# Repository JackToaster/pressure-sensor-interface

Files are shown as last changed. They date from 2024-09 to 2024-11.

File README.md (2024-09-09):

# Pressure Sensor Interface

This repository contains PCB designs & firmware (WIP) for an 8-channel USB pressure sensor/solenoid valve driver.

## Features

(Note that this is still in the early prototype stage so these specs have not been validated yet)

**8x pressure sensors**

- using the LWPxxx series of low-cost piezoresistive pressure sensors
- HX711 Load cell amplifier to read output
  - Note the full scale range of the pressure sensor is wider than the input range of the HX711 - This means the full range of the sensor may be impossible to read, but this is an acceptable tradeoff for the extremely low cost.
  - Capable of up to 144Hz sampling rate
 
**8x Solenoid Valve Drivers**

- Low-side NMOS switches
- Capable of ~4A per channel
- Separate DC power input for solenoid valves, supports 0-24VDC (Limited by 30V Vds rating of FET)
- Individual PWM control of each channel

**STM32F103 Microcontroller + USB-C**

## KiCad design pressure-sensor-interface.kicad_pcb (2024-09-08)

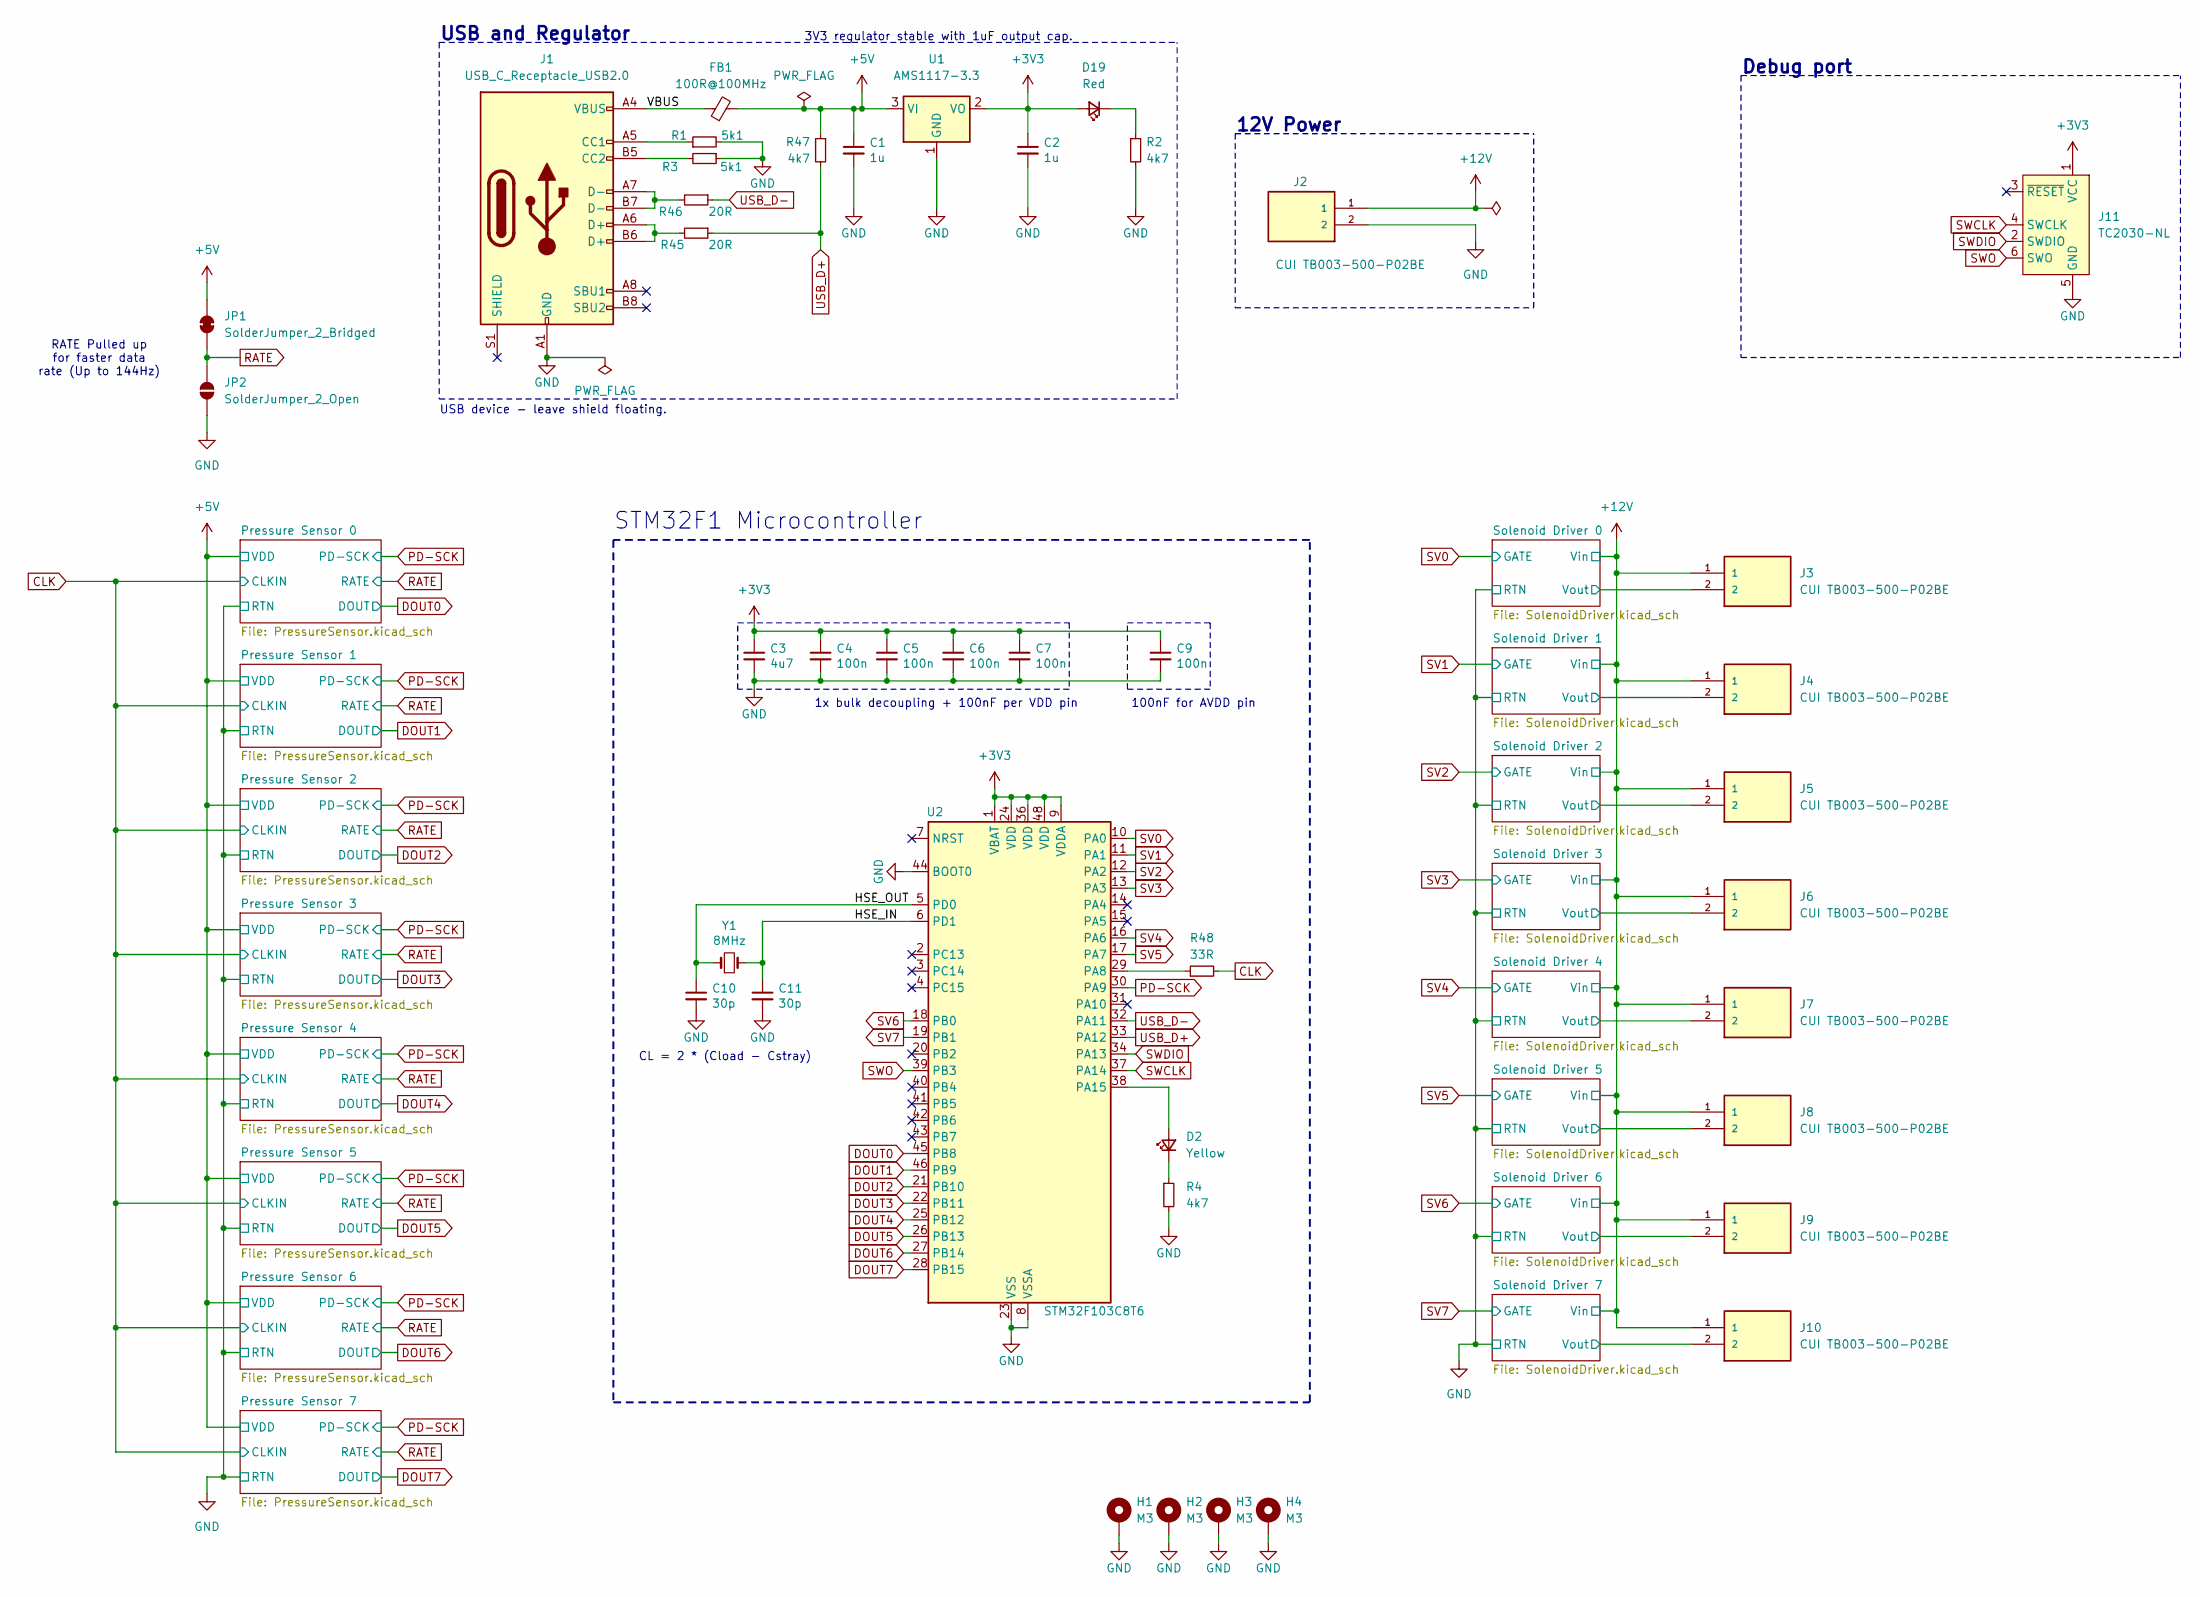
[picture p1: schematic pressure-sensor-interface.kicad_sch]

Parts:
C1, C2: 1u; C_0603_1608Metric; LCSC C15849
C3: 4u7; C_0603_1608Metric; LCSC C19666
C4, C5, C6, C7, C9: 100n; C_0603_1608Metric; LCSC C307331
C10, C11: 30p; C_0603_1608Metric; LCSC C1570
D2: Yellow; LED_0603_1608Metric
D19: Red; LED_0603_1608Metric
FB1: 100R@100MHz; R_0805_2012Metric; LCSC C1015
H1, H2, H3, H4: M3; MountingHole_2.2mm_M2_Pad_Via
J1: USB_C_Receptacle_USB2.0; USB_C_Receptacle_HRO_TYPE-C-31-M-12; LCSC C165948
J2, J3, J4, J5, J6, J7, J8, J9, J10: CUI TB003-500-P02BE; CUI_TB003-500-P02BE
J11: TC2030-NL; Tag-Connect_TC2030-IDC-NL_2x03_P1.27mm_Vertical
JP1: SolderJumper_2_Bridged; SolderJumper-2_P1.3mm_Bridged_Pad1.0x1.5mm
JP2: SolderJumper_2_Open; SolderJumper-2_P1.3mm_Open_TrianglePad1.0x1.5mm
R1, R3: 5k1; R_0603_1608Metric; LCSC C25905
R2, R4, R47: 4k7; R_0603_1608Metric
R45, R46: 20R; R_0603_1608Metric; LCSC C25905
R48: 33R; R_0603_1608Metric
U1: AMS1117-3.3; SOT-223-3_TabPin2; LCSC C6186
U2: STM32F103C8T6; LQFP-48_7x7mm_P0.5mm; LCSC C77994
Y1: 8MHz; Crystal_SMD_5032-2Pin_5.0x3.2mm; LCSC C115962

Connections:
+3V3: C2.1, C3.1, C4.1, C5.1, C6.1, C7.1, C9.1, D19.2 (A), J11.1 (VCC), U1.2 (VO), U2.1 (VBAT), U2.9 (VDDA), U2.24 (VDD), U2.36 (VDD), U2.48 (VDD)
+5V: C1.1, FB1.2, JP1.2 (B), R47.1, U1.3 (VI); also elsewhere on the board
+12V: J2.1, J3.1, J4.1, J5.1, J6.1, J7.1, J8.1, J9.1, J10.1; also elsewhere on the board
/HSE_IN: C11.1, U2.6 (PD1), Y1.2
/HSE_OUT: C10.1, U2.5 (PD0), Y1.1
/Solenoid Driver 0/Vout: J3.2; also elsewhere on the board
/Solenoid Driver 1/Vout: J4.2; also elsewhere on the board
/Solenoid Driver 2/Vout: J5.2; also elsewhere on the board
/Solenoid Driver 3/Vout: J6.2; also elsewhere on the board
/Solenoid Driver 4/Vout: J7.2; also elsewhere on the board
/Solenoid Driver 5/Vout: J8.2; also elsewhere on the board
/Solenoid Driver 6/Vout: J9.2; also elsewhere on the board
/Solenoid Driver 7/Vout: J10.2; also elsewhere on the board
/VBUS: FB1.1, J1.A4 (VBUS), J1.A9 (VBUS), J1.B4 (VBUS), J1.B9 (VBUS)
CLK: R48.2; also elsewhere on the board
DOUT0: U2.45 (PB8); also elsewhere on the board
DOUT1: U2.46 (PB9); also elsewhere on the board
DOUT2: U2.21 (PB10); also elsewhere on the board
DOUT3: U2.22 (PB11); also elsewhere on the board
DOUT4: U2.25 (PB12); also elsewhere on the board
DOUT5: U2.26 (PB13); also elsewhere on the board
DOUT6: U2.27 (PB14); also elsewhere on the board
DOUT7: U2.28 (PB15); also elsewhere on the board
GND: C1.2, C2.2, C3.2, C4.2, C5.2, C6.2, C7.2, C9.2, C10.2, C11.2, H1.1, H2.1, H3.1, H4.1, J1.A1 (GND), J1.A12 (GND), J1.B1 (GND), J1.B12 (GND), J2.2, J11.5 (GND), JP2.1 (A), R1.2, R2.2, R3.1, R4.2, U1.1 (GND), U2.8 (VSSA), U2.23 (VSS), U2.35 (VSS), U2.44 (BOOT0), U2.47 (VSS); also elsewhere on the board
unnamed: D2.2 (A), U2.38 (PA15)
unnamed: D2.1 (K), R4.1
unnamed: D19.1 (K), R2.1
unnamed: J1.A5 (CC1), R1.1
unnamed: J1.B5 (CC2), R3.2
unnamed: J1.A6 (D+), J1.B6 (D+), R45.2
unnamed: J1.A7 (D-), J1.B7 (D-), R46.2
unnamed: R48.1, U2.29 (PA8)
PD-SCK: U2.30 (PA9); also elsewhere on the board
RATE: JP1.1 (A), JP2.2 (B); also elsewhere on the board
SV0: U2.10 (PA0); also elsewhere on the board
SV1: U2.11 (PA1); also elsewhere on the board
SV2: U2.12 (PA2); also elsewhere on the board
SV3: U2.13 (PA3); also elsewhere on the board
SV4: U2.16 (PA6); also elsewhere on the board
SV5: U2.17 (PA7); also elsewhere on the board
SV6: U2.18 (PB0); also elsewhere on the board
SV7: U2.19 (PB1); also elsewhere on the board
SWCLK: J11.4 (SWCLK), U2.37 (PA14)
SWDIO: J11.2 (SWDIO), U2.34 (PA13)
SWO: J11.6 (SWO), U2.39 (PB3)
USB_D+: R45.1, R47.2, U2.33 (PA12)
USB_D-: R46.1, U2.32 (PA11)

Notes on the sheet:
12V Power
Debug port
USB and Regulator
3V3 regulator stable with 1uF output cap.
RATE Pulled up for faster data rate (Up to 144Hz)
100nF for AVDD pin
1x bulk decoupling + 100nF per VDD pin
CL = 2 * (Cload - Cstray)
STM32F1 Microcontroller
USB device - leave shield floating.

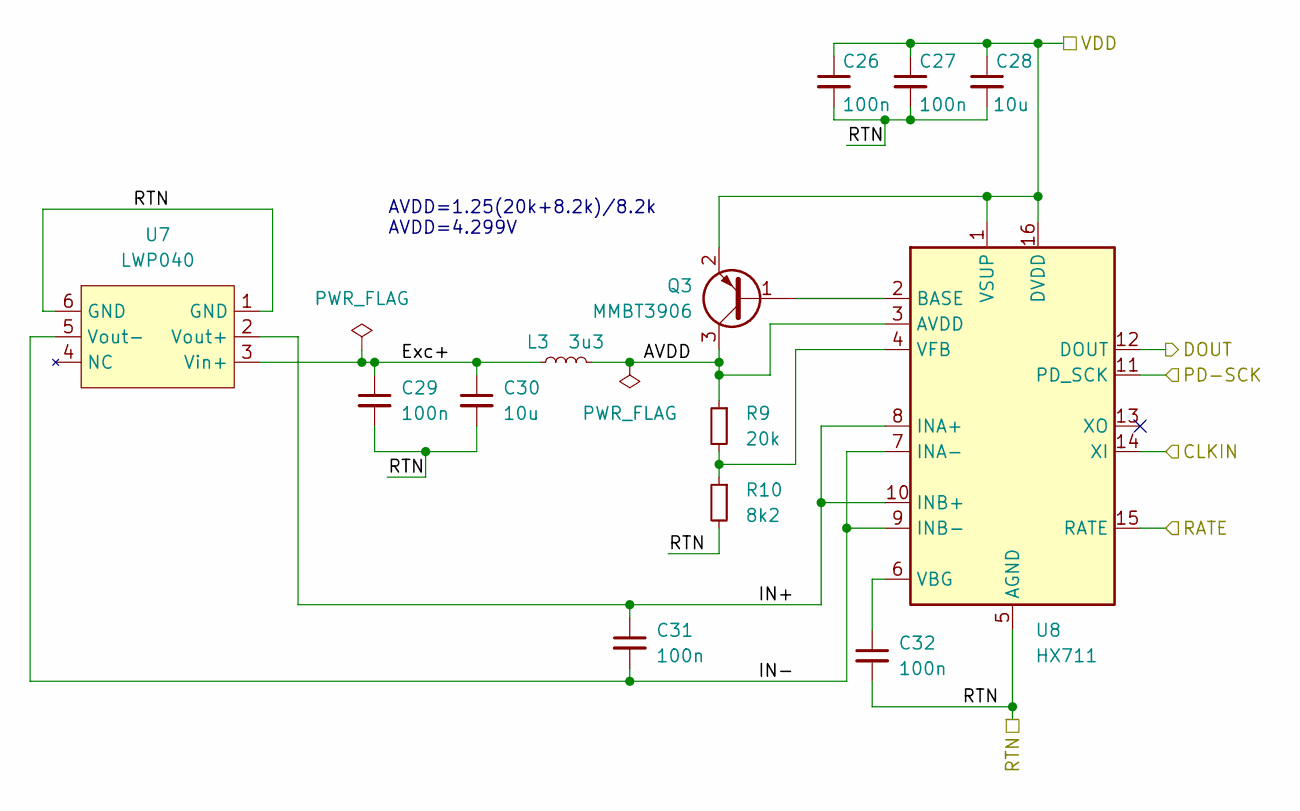
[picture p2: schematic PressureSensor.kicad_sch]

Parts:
C26, C27, C29, C31, C32: 100n; C_0603_1608Metric
C28, C30: 10u; C_0603_1608Metric
L3: 3u3; L_0603_1608Metric
Q3: MMBT3906; SOT-23
R9: 20k; R_0603_1608Metric
R10: 8k2; R_0603_1608Metric
U7: LWP040; SOIC-6-Pressure-Sensor
U8: HX711; SOP-16_3.9x9.9mm_P1.27mm

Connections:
+5V: C26.1, C27.1, C28.1, Q3.2 (E), U8.1 (VSUP), U8.16 (DVDD); also elsewhere on the board
/Pressure Sensor 2/AVDD: L3.2, Q3.3 (C), R9.1, U8.3 (AVDD)
/Pressure Sensor 2/Exc+: C29.1, C30.1, L3.1, U7.3 (Vin+)
/Pressure Sensor 2/IN+: C31.1, U7.2 (Vout+), U8.8 (INA+), U8.10 (INB+)
/Pressure Sensor 2/IN-: C31.2, U7.5 (Vout-), U8.7 (INA-), U8.9 (INB-)
CLK: U8.14 (XI); also elsewhere on the board
DOUT2: U8.12 (DOUT); also elsewhere on the board
GND: C26.2, C27.2, C28.2, C29.2, C30.2, C32.2, R10.2, U7.1 (GND), U7.6 (GND), U8.5 (AGND); also elsewhere on the board
unnamed: Q3.1 (B), U8.2 (BASE)
unnamed: C32.1, U8.6 (VBG)
unnamed: R9.2, R10.1, U8.4 (VFB)
PD-SCK: U8.11 (PD_SCK); also elsewhere on the board
RATE: U8.15 (RATE); also elsewhere on the board

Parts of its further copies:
C12, C13, C15, C17, C18, C19, C20, C22, C24, C25, C33, C34, C36, C38, C39, C40, C41, C43, C45, C46, C47, C48, C50, C52, C53, C54, C55, C57, C59, C60, C61, C62, C64, C66, C67: 100n; C_0603_1608Metric
C14, C16, C21, C23, C35, C37, C42, C44, C49, C51, C56, C58, C63, C65: 10u; C_0603_1608Metric
L1, L2, L4, L5, L6, L7, L8: 3u3; L_0603_1608Metric
Q1, Q2, Q4, Q5, Q6, Q7, Q8: MMBT3906; SOT-23
R5, R7, R11, R13, R15, R17, R19: 20k; R_0603_1608Metric
R6, R8, R12, R14, R16, R18, R20: 8k2; R_0603_1608Metric
U3, U5, U9, U11, U13, U15, U17: LWP040; SOIC-6-Pressure-Sensor
U4, U6, U10, U12, U14, U16, U18: HX711; SOP-16_3.9x9.9mm_P1.27mm

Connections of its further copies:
+5V: C12.1, C13.1, C14.1, C19.1, C20.1, C21.1, C33.1, C34.1, C35.1, C40.1, C41.1, C42.1, C47.1, C48.1, C49.1, C54.1, C55.1, C56.1, C61.1, C62.1, C63.1, Q1.2 (E), Q2.2 (E), Q4.2 (E), Q5.2 (E), Q6.2 (E), Q7.2 (E), Q8.2 (E), U4.1 (VSUP), U4.16 (DVDD), U6.1 (VSUP), U6.16 (DVDD), U10.1 (VSUP), U10.16 (DVDD), U12.1 (VSUP), U12.16 (DVDD), U14.1 (VSUP), U14.16 (DVDD), U16.1 (VSUP), U16.16 (DVDD), U18.1 (VSUP), U18.16 (DVDD); also elsewhere on the board
/Pressure Sensor 0/AVDD: L1.2, Q1.3 (C), R5.1, U4.3 (AVDD)
/Pressure Sensor 0/Exc+: C15.1, C16.1, L1.1, U3.3 (Vin+)
/Pressure Sensor 0/IN+: C17.1, U3.2 (Vout+), U4.8 (INA+), U4.10 (INB+)
/Pressure Sensor 0/IN-: C17.2, U3.5 (Vout-), U4.7 (INA-), U4.9 (INB-)
/Pressure Sensor 1/AVDD: L2.2, Q2.3 (C), R7.1, U6.3 (AVDD)
/Pressure Sensor 1/Exc+: C22.1, C23.1, L2.1, U5.3 (Vin+)
/Pressure Sensor 1/IN+: C24.1, U5.2 (Vout+), U6.8 (INA+), U6.10 (INB+)
/Pressure Sensor 1/IN-: C24.2, U5.5 (Vout-), U6.7 (INA-), U6.9 (INB-)
/Pressure Sensor 3/AVDD: L4.2, Q4.3 (C), R11.1, U10.3 (AVDD)
/Pressure Sensor 3/Exc+: C36.1, C37.1, L4.1, U9.3 (Vin+)
/Pressure Sensor 3/IN+: C38.1, U9.2 (Vout+), U10.8 (INA+), U10.10 (INB+)
/Pressure Sensor 3/IN-: C38.2, U9.5 (Vout-), U10.7 (INA-), U10.9 (INB-)
/Pressure Sensor 4/AVDD: L5.2, Q5.3 (C), R13.1, U12.3 (AVDD)
/Pressure Sensor 4/Exc+: C43.1, C44.1, L5.1, U11.3 (Vin+)
/Pressure Sensor 4/IN+: C45.1, U11.2 (Vout+), U12.8 (INA+), U12.10 (INB+)
/Pressure Sensor 4/IN-: C45.2, U11.5 (Vout-), U12.7 (INA-), U12.9 (INB-)
/Pressure Sensor 5/AVDD: L6.2, Q6.3 (C), R15.1, U14.3 (AVDD)
/Pressure Sensor 5/Exc+: C50.1, C51.1, L6.1, U13.3 (Vin+)
/Pressure Sensor 5/IN+: C52.1, U13.2 (Vout+), U14.8 (INA+), U14.10 (INB+)
/Pressure Sensor 5/IN-: C52.2, U13.5 (Vout-), U14.7 (INA-), U14.9 (INB-)
/Pressure Sensor 6/AVDD: L7.2, Q7.3 (C), R17.1, U16.3 (AVDD)
/Pressure Sensor 6/Exc+: C57.1, C58.1, L7.1, U15.3 (Vin+)
/Pressure Sensor 6/IN+: C59.1, U15.2 (Vout+), U16.8 (INA+), U16.10 (INB+)
/Pressure Sensor 6/IN-: C59.2, U15.5 (Vout-), U16.7 (INA-), U16.9 (INB-)
/Pressure Sensor 7/AVDD: L8.2, Q8.3 (C), R19.1, U18.3 (AVDD)
/Pressure Sensor 7/Exc+: C64.1, C65.1, L8.1, U17.3 (Vin+)
/Pressure Sensor 7/IN+: C66.1, U17.2 (Vout+), U18.8 (INA+), U18.10 (INB+)
/Pressure Sensor 7/IN-: C66.2, U17.5 (Vout-), U18.7 (INA-), U18.9 (INB-)
CLK: U4.14 (XI), U6.14 (XI), U10.14 (XI), U12.14 (XI), U14.14 (XI), U16.14 (XI), U18.14 (XI); also elsewhere on the board
DOUT0: U4.12 (DOUT); also elsewhere on the board
DOUT1: U6.12 (DOUT); also elsewhere on the board
DOUT3: U10.12 (DOUT); also elsewhere on the board
DOUT4: U12.12 (DOUT); also elsewhere on the board
DOUT5: U14.12 (DOUT); also elsewhere on the board
DOUT6: U16.12 (DOUT); also elsewhere on the board
DOUT7: U18.12 (DOUT); also elsewhere on the board
GND: C12.2, C13.2, C14.2, C15.2, C16.2, C18.2, C19.2, C20.2, C21.2, C22.2, C23.2, C25.2, C33.2, C34.2, C35.2, C36.2, C37.2, C39.2, C40.2, C41.2, C42.2, C43.2, C44.2, C46.2, C47.2, C48.2, C49.2, C50.2, C51.2, C53.2, C54.2, C55.2, C56.2, C57.2, C58.2, C60.2, C61.2, C62.2, C63.2, C64.2, C65.2, C67.2, R6.2, R8.2, R12.2, R14.2, R16.2, R18.2, R20.2, U3.1 (GND), U3.6 (GND), U4.5 (AGND), U5.1 (GND), U5.6 (GND), U6.5 (AGND), U9.1 (GND), U9.6 (GND), U10.5 (AGND), U11.1 (GND), U11.6 (GND), U12.5 (AGND), U13.1 (GND), U13.6 (GND), U14.5 (AGND), U15.1 (GND), U15.6 (GND), U16.5 (AGND), U17.1 (GND), U17.6 (GND), U18.5 (AGND); also elsewhere on the board
unnamed: Q1.1 (B), U4.2 (BASE)
unnamed: Q2.1 (B), U6.2 (BASE)
unnamed: Q4.1 (B), U10.2 (BASE)
unnamed: Q5.1 (B), U12.2 (BASE)
unnamed: Q6.1 (B), U14.2 (BASE)
unnamed: Q7.1 (B), U16.2 (BASE)
unnamed: Q8.1 (B), U18.2 (BASE)
unnamed: C18.1, U4.6 (VBG)
unnamed: R5.2, R6.1, U4.4 (VFB)
unnamed: C25.1, U6.6 (VBG)
unnamed: R7.2, R8.1, U6.4 (VFB)
unnamed: C39.1, U10.6 (VBG)
unnamed: R11.2, R12.1, U10.4 (VFB)
unnamed: C46.1, U12.6 (VBG)
unnamed: R13.2, R14.1, U12.4 (VFB)
unnamed: C53.1, U14.6 (VBG)
unnamed: R15.2, R16.1, U14.4 (VFB)
unnamed: C60.1, U16.6 (VBG)
unnamed: R17.2, R18.1, U16.4 (VFB)
unnamed: C67.1, U18.6 (VBG)
unnamed: R19.2, R20.1, U18.4 (VFB)
PD-SCK: U4.11 (PD_SCK), U6.11 (PD_SCK), U10.11 (PD_SCK), U12.11 (PD_SCK), U14.11 (PD_SCK), U16.11 (PD_SCK), U18.11 (PD_SCK); also elsewhere on the board
RATE: U4.15 (RATE), U6.15 (RATE), U10.15 (RATE), U12.15 (RATE), U14.15 (RATE), U16.15 (RATE), U18.15 (RATE); also elsewhere on the board

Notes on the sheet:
AVDD=1.25(20k+8.2k)/8.2k AVDD=4.299V

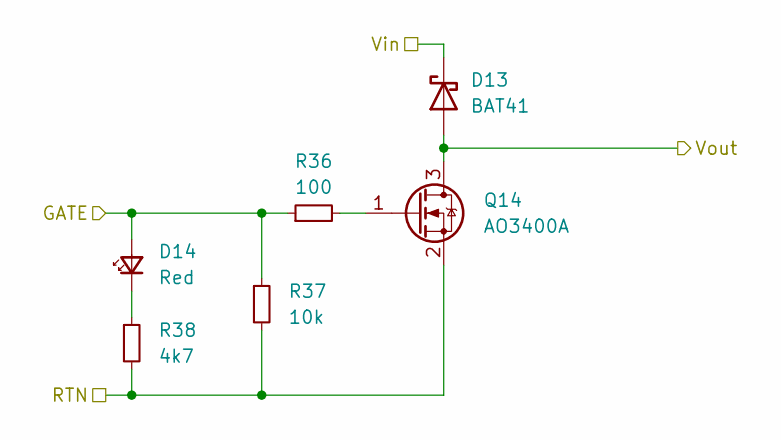
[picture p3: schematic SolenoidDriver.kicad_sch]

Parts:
D13: BAT41; D_SOD-123
D14: Red; LED_0603_1608Metric
Q14: AO3400A; SOT-23
R36: 100; R_0603_1608Metric
R37: 10k; R_0603_1608Metric
R38: 4k7; R_0603_1608Metric

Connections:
+12V: D13.1 (K); also elsewhere on the board
/Solenoid Driver 5/Vout: D13.2 (A), Q14.3 (D); also elsewhere on the board
GND: Q14.2 (S), R37.2, R38.2; also elsewhere on the board
unnamed: D14.1 (K), R38.1
unnamed: Q14.1 (G), R36.2
SV5: D14.2 (A), R36.1, R37.1; also elsewhere on the board

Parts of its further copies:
D3, D5, D7, D9, D11, D15, D17: BAT41; D_SOD-123
D4, D6, D8, D10, D12, D16, D18: Red; LED_0603_1608Metric
Q9, Q10, Q11, Q12, Q13, Q15, Q16: AO3400A; SOT-23
R21, R24, R27, R30, R33, R39, R42: 100; R_0603_1608Metric
R22, R25, R28, R31, R34, R40, R43: 10k; R_0603_1608Metric
R23, R26, R29, R32, R35, R41, R44: 4k7; R_0603_1608Metric

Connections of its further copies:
+12V: D3.1 (K), D5.1 (K), D7.1 (K), D9.1 (K), D11.1 (K), D15.1 (K), D17.1 (K); also elsewhere on the board
/Solenoid Driver 0/Vout: D3.2 (A), Q9.3 (D); also elsewhere on the board
/Solenoid Driver 1/Vout: D5.2 (A), Q10.3 (D); also elsewhere on the board
/Solenoid Driver 2/Vout: D7.2 (A), Q11.3 (D); also elsewhere on the board
/Solenoid Driver 3/Vout: D9.2 (A), Q12.3 (D); also elsewhere on the board
/Solenoid Driver 4/Vout: D11.2 (A), Q13.3 (D); also elsewhere on the board
/Solenoid Driver 6/Vout: D15.2 (A), Q15.3 (D); also elsewhere on the board
/Solenoid Driver 7/Vout: D17.2 (A), Q16.3 (D); also elsewhere on the board
GND: Q9.2 (S), Q10.2 (S), Q11.2 (S), Q12.2 (S), Q13.2 (S), Q15.2 (S), Q16.2 (S), R22.2, R23.2, R25.2, R26.2, R28.2, R29.2, R31.2, R32.2, R34.2, R35.2, R40.2, R41.2, R43.2, R44.2; also elsewhere on the board
unnamed: D4.1 (K), R23.1
unnamed: D6.1 (K), R26.1
unnamed: D8.1 (K), R29.1
unnamed: D10.1 (K), R32.1
unnamed: D12.1 (K), R35.1
unnamed: D16.1 (K), R41.1
unnamed: D18.1 (K), R44.1
unnamed: Q9.1 (G), R21.2
unnamed: Q10.1 (G), R24.2
unnamed: Q11.1 (G), R27.2
unnamed: Q12.1 (G), R30.2
unnamed: Q13.1 (G), R33.2
unnamed: Q15.1 (G), R39.2
unnamed: Q16.1 (G), R42.2
SV0: D4.2 (A), R21.1, R22.1; also elsewhere on the board
SV1: D6.2 (A), R24.1, R25.1; also elsewhere on the board
SV2: D8.2 (A), R27.1, R28.1; also elsewhere on the board
SV3: D10.2 (A), R30.1, R31.1; also elsewhere on the board
SV4: D12.2 (A), R33.1, R34.1; also elsewhere on the board
SV6: D16.2 (A), R39.1, R40.1; also elsewhere on the board
SV7: D18.2 (A), R42.1, R43.1; also elsewhere on the board

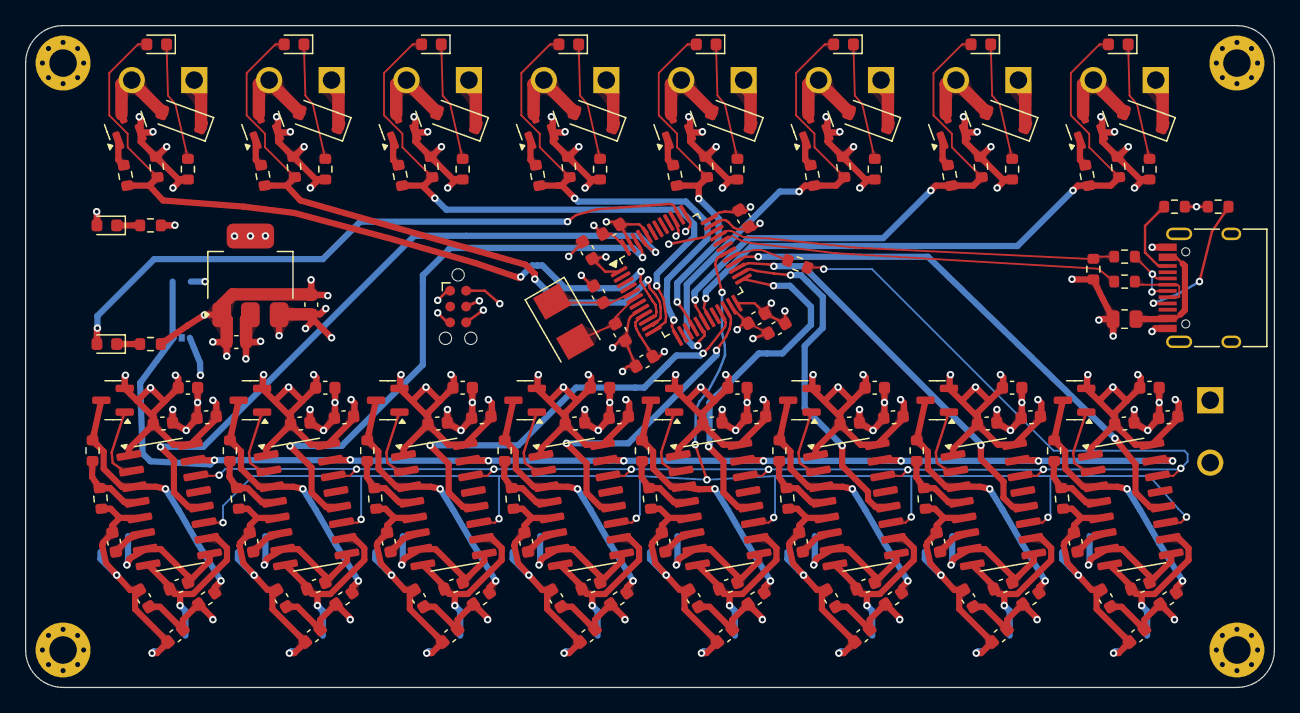
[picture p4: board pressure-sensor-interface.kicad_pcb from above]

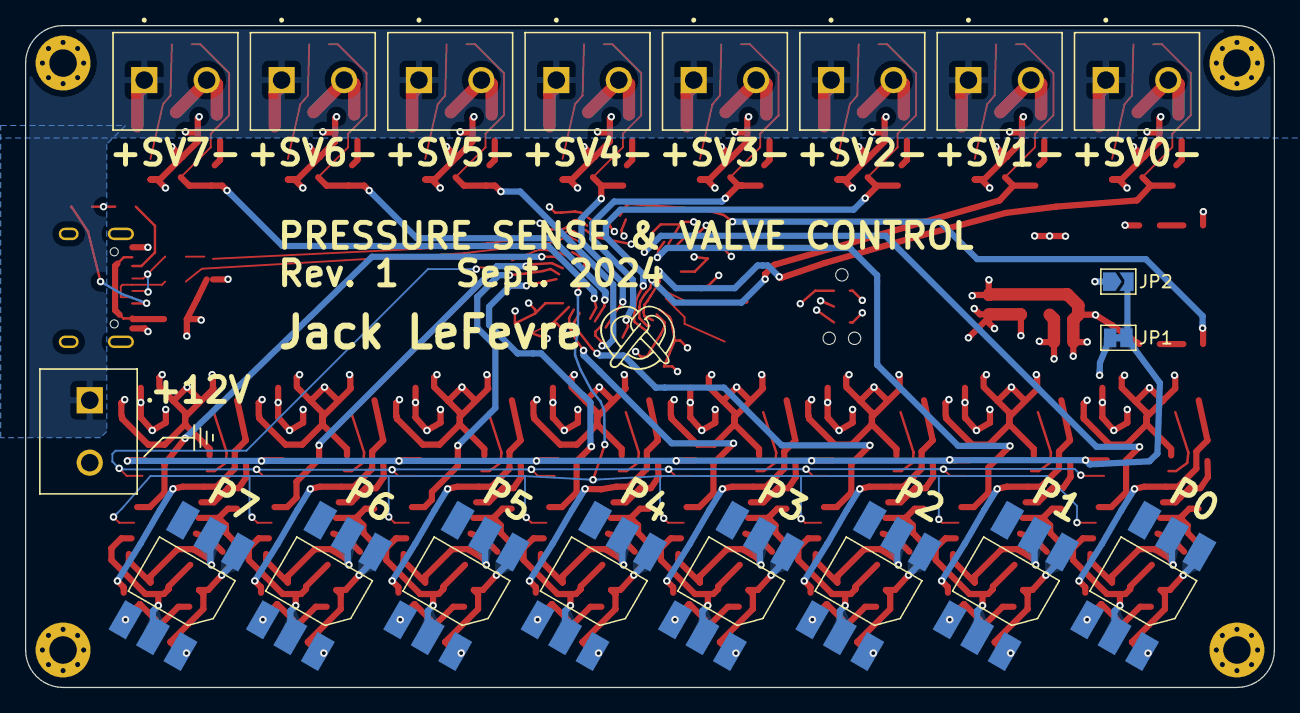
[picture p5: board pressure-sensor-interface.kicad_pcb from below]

Board: 4 copper layers, 100.0 x 53.0 mm, 193 parts (19 on the bottom side), 119 nets.

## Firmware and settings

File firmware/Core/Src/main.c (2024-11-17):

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
/* Includes ------------------------------------------------------------------*/
#include "main.h"
#include "crc.h"
#include "tim.h"
#include "usb_device.h"
#include "gpio.h"

/* USER CODE BEGIN Includes */
#include "usbd_cdc_if.h"
#include "hx711.h"
#include "stm32f1xx_hal_crc.h"
#include "valve.h"
/* USER CODE END Includes */


void SystemClock_Config(void);
/* USER CODE BEGIN 0 */
volatile uint32_t crc1, crc2;

struct TxStruct tx_data = {};


uint32_t crc32_native(uint32_t *bfr, int len_words, int clear) {
    uint32_t *bfr2 = bfr;
    int len_words_2 = len_words;
    if(clear)
    {
        __HAL_CRC_DR_RESET(&hcrc);
    }

    while(len_words--)
    {
        uint32_t buf_val = *bfr++;
        
        hcrc.Instance->DR = __REV(buf_val);
    }
    hcrc.State = HAL_CRC_STATE_READY;

    return hcrc.Instance->DR;
}

void build_tx_data(void) {
  for(uint8_t channel = 0; channel < 8; channel++) {
    tx_data.pressures[channel] = hx711_get_kpa(channel);
  }


  uint32_t crc = crc32_native((uint32_t*) &tx_data, sizeof(struct TxStruct) / 4 - 1, 1);
  tx_data.crc = crc;
}

#define TX_BUF_LEN sizeof(tx_data)


volatile float tick_rate;
uint32_t loop_count;

/* USER CODE END 0 */

/**
  * @brief  The application entry point.
  * @retval int
  */
int main(void)
{
  /* MCU Configuration--------------------------------------------------------*/

  /* Reset of all peripherals, Initializes the Flash interface and the Systick. */
  HAL_Init();

  /* Configure the system clock */
  SystemClock_Config();

  /* Initialize all configured peripherals */
  MX_GPIO_Init();
  MX_TIM1_Init();
  MX_TIM2_Init();
  MX_TIM3_Init();
  MX_USB_DEVICE_Init();
  MX_CRC_Init();
  /* USER CODE BEGIN 2 */
  valve_init();

  HAL_TIM_PWM_Start(&htim1, TIM_CHANNEL_1);

  hx711_initialize(GAIN_32_PULSES);
  hx711_zero();

  tx_data.magic[0] = 'P';
  tx_data.magic[1] = 'R';
  tx_data.magic[2] = 'Z';
  tx_data.magic[3] = 'L';
  

  // uint32_t switch_time = 10;
  // while(switch_time > 5) {
  //   for(uint8_t j = 0; j < 64; ++j) {
  //     valve_states[0] = 1;
  //     HAL_Delay(switch_time);
  //     valve_states[0] = 0;
  //     HAL_Delay(switch_time);
  //   }
      
  //   HAL_Delay(500);
  //   switch_time -= 1;
  // }
  
  
  /* USER CODE END 2 */

  /* Infinite loop */
  /* USER CODE BEGIN WHILE */
  while (1)
  {
    hx711_read();
    
    build_tx_data();

    CDC_Transmit_FS((uint8_t*)&tx_data, TX_BUF_LEN);


    float p0 = hx711_get_kpa(0);
    
    float hyst_on = 0.2;
    float hyst_off = 0.2;

    float target = 4.5;

    // fill valve
    if(p0 < target - hyst_on ) {
      valve_states[0] = 1; // open
    } else if (p0 > target - hyst_off) {
      valve_states[0] = 0; // close
    }

    // drain valve
    if(p0 < target + hyst_off) {
      valve_states[1] = 0; // close
    } else if (p0 > target + hyst_on) {
      valve_states[1] = 1; // open
    }

    loop_count++;
    tick_rate = (float)(HAL_GetTick()) / (float)loop_count;


    /* USER CODE END WHILE */

    /* USER CODE BEGIN 3 */
  }
  /* USER CODE END 3 */
}

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


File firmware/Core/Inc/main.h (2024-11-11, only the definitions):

#define DOUT2_Pin GPIO_PIN_10
#define DOUT2_GPIO_Port GPIOB
#define DOUT3_Pin GPIO_PIN_11
#define DOUT3_GPIO_Port GPIOB
#define DOUT4_Pin GPIO_PIN_12
#define DOUT4_GPIO_Port GPIOB
#define DOUT5_Pin GPIO_PIN_13
#define DOUT5_GPIO_Port GPIOB
#define DOUT6_Pin GPIO_PIN_14
#define DOUT6_GPIO_Port GPIOB
#define DOUT7_Pin GPIO_PIN_15
#define DOUT7_GPIO_Port GPIOB
#define CLK_Pin GPIO_PIN_8
#define CLK_GPIO_Port GPIOA
#define PD_SCK_Pin GPIO_PIN_9
#define PD_SCK_GPIO_Port GPIOA
#define DOUT0_Pin GPIO_PIN_8
#define DOUT0_GPIO_Port GPIOB
#define DOUT1_Pin GPIO_PIN_9
#define DOUT1_GPIO_Port GPIOB

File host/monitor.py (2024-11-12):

import struct
import serial
import crcmod
import threading
import time
from queue import Queue

# Constants
SERIAL_PORT = "/dev/ttyACM2"  # Replace with your serial port
BAUDRATE = 115200
MAGIC = b'PRZL'  # Expected magic bytes
PACKET_SIZE = 4 + 8 * 4 + 4  # 4 bytes for magic, 8 floats, 4 bytes for CRC


def calculate_crc(data):
    pcrc = crcmod.Crc(0x104c11db7, initCrc=0xffffffff, rev=False)
    pcrc.update(data)
    return pcrc.crcValue


def ser_read_thread(ser):
    while True:
        # Read the expected packet size from the serial port
        raw_data = ser.read(PACKET_SIZE)

        if len(raw_data) != PACKET_SIZE:
            print("Incomplete packet received")
            continue

        # Unpack the packet
        try:
            unpacked_data = struct.unpack('<4s8fI', raw_data)
            magic = unpacked_data[0]
            pressures = unpacked_data[1:9]
            received_crc = unpacked_data[9]

            # Check magic bytes
            if magic != MAGIC:
                print("Magic bytes mismatch. Discarding packet.")
                continue

            # Calculate CRC on the received data except the last 4 bytes (the CRC)
            data_for_crc = raw_data[0:-4]
            calculated_crc = calculate_crc(data_for_crc)

            # Verify CRC
            if calculated_crc != received_crc:
                print(f"CRC mismatch! Expected: {received_crc:#010x}, Calculated: {calculated_crc:#010x}")
                continue

            # If everything checks out, print the pressures
            # print("Received pressures:", pressures)

        except struct.error as e:
            print("Failed to unpack data:", e)


# Main function to read and parse data
def read_serial_data():
    with serial.Serial(SERIAL_PORT, BAUDRATE, timeout=1) as ser:
        read_thread = threading.Thread(target=ser_read_thread, args=(ser,), daemon=True)
        read_thread.start()


# Run the function
if __name__ == "__main__":
    read_serial_data()

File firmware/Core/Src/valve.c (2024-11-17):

#include "valve.h"

uint8_t valve_inited = 0;

uint8_t valve_states[N_VALVES];

uint32_t valve_timers[N_VALVES];

extern TIM_HandleTypeDef htim2, htim3;

void set_valve_pwms(void) {
    uint16_t pwm_values[8] = { 0 };

    for(uint8_t i = 0; i < N_VALVES; ++i) {
        if(valve_states[i]) {
            if(valve_timers[i] < HIT_TIME) {
                pwm_values[i] = HIT_PWM;
            } else {
                pwm_values[i] = HOLD_PWM;
            }
        } else {
            pwm_values[i] = 0;
        }
    }
    htim2.Instance->CCR1 = pwm_values[0];
    htim2.Instance->CCR2 = pwm_values[1];
    htim2.Instance->CCR3 = pwm_values[2];
    htim2.Instance->CCR4 = pwm_values[3];

    htim3.Instance->CCR1 = pwm_values[4];
    htim3.Instance->CCR2 = pwm_values[5];
    htim3.Instance->CCR3 = pwm_values[6];
    htim3.Instance->CCR4 = pwm_values[7];
}

void valve_init(void) {
    valve_inited = 1;
    for(uint8_t i = 0; i < N_VALVES; ++i) {
        valve_states[i] = 0;
        valve_timers[i] = 0;
    }
    set_valve_pwms();

    HAL_TIM_PWM_Start(&htim2, TIM_CHANNEL_1);
    HAL_TIM_PWM_Start(&htim2, TIM_CHANNEL_2);
    HAL_TIM_PWM_Start(&htim2, TIM_CHANNEL_3);
    HAL_TIM_PWM_Start(&htim2, TIM_CHANNEL_4);

    HAL_TIM_PWM_Start(&htim3, TIM_CHANNEL_1);
    HAL_TIM_PWM_Start(&htim3, TIM_CHANNEL_2);
    HAL_TIM_PWM_Start(&htim3, TIM_CHANNEL_3);
    HAL_TIM_PWM_Start(&htim3, TIM_CHANNEL_4);
}

void valve_update(void) {
    if(valve_inited == 0) {
        return;
    }
    for(uint8_t i = 0; i < N_VALVES; ++i) {
        if(valve_states[i]) {
            if(valve_timers[i] < HIT_TIME) {
                valve_timers[i]++;
            }
        } else {
            valve_timers[i] = 0;
        }
    }

    set_valve_pwms();
}

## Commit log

2024-09-08 initial commit, created layout
    [PressureSensor.kicad_sch, SolenoidDriver.kicad_sch, pressure-sensor-interface.kicad_pcb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]
2024-11-17 test valve control
2024-11-30 added manual and auto valve control

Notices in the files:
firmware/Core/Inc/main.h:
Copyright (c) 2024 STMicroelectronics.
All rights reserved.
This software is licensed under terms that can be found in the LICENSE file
